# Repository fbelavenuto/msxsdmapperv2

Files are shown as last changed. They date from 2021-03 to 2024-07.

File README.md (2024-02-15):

# MSX SD Mapper V2

## WARNING: do not try to update the old SDMapper V1 (and its clones) with this new ROM using the old SDMUPD.COM utility, as the hardware is different, and it will brick your cartridge.

# Disclaimer

This documentation describes Open Hardware and is licensed under the CERN OHL v. 1.1.

You may redistribute and modify this documentation under the terms of the [CERN OHL v.1.1](http://ohwr.org/cernohl). This documentation is distributed WITHOUT ANY EXPRESS OR IMPLIED WARRANTY, INCLUDING OF MERCHANTABILITY, SATISFACTORY QUALITY AND FITNESS FOR A PARTICULAR PURPOSE.

Please see the CERN OHL v.1.1 for applicable conditions

# Project description

This project implements a cartridge-shaped interface to add a mass storage device using up to two SD (Secure Digital) and a 512K Mapper for MSX line computers.

[Nextor](http://www.konamiman.com/msx/msx-e.html#nextor) was used as operating system, being developed only the driver to have access to the two SD cards. Nextor is an open project.

Nextor is an evolution of MSX-DOS 2 natively supporting FAT16 partitions up to 4GB, and can have 4 partitions per SD card. 128KB of Mapper is required on the minimum to use Nextor with access to sub-directories, less than 128K mapper only allows the use of the MSXDOS1 kernel, limiting partitions with FAT12 and maximum 16MB per partition.

One of the switches enables or disables the Mapper in conjunction with a slot expander. The second key allows you to select between two driver options, useful for having a backup a stable version of the driver and use it to restore a new driver update failed.

A utility called "FBL-UPD.COM" was created to be able to update the flash by MSX itself.

To compile the FBL-UPD.COM driver and utility use the [Konaniman's Nestor80](https://github.com/Konamiman/Nestor80) and to compile the CPLD code use [Xilinx ISE Webpack](https://www.xilinx.com/support/download/index.html/content/xilinx/en/downloadNav/vivado-design-tools/archive-ise.html).

Technical details:
 - The CPLD code implements all the necessary logic, implementing an expander of standard slots, one SPI mode 0 port, standard ASCII16 MegaROM control used by Nextor and the 512K Mapper control.
 - When activating the mapper, the interface activates the slot expander, and with that the interface works only on non-expanded slots. However, if you disable the mapper, the slot expander is disabled, allowing you to use the device of mass storage in expanded slots. the mass storage device is in subslot 0 and the mapper device in subslot 1.
 - There is a window in $7B00~7EFF for SPI data transfer.
 - There is a configuration and status register at address $7FF0 and a small timer at address $7FF1. More details in the driver source.

# Acknowledge

Thanks to FRS for rewriting the driver, to Luciano Sturaro for board routing and the MSXBR-L community for their support and encouragement.

# Quickstart guide

After assembling the device, or buying a ready-made one, get an SD card, put it in the interface and start MSX.

When dropping into BASIC, type `CALL FDISK` to start formatting the SD card. The FAT16 file system used by Nextor supports a maximum of 4GB.

After partitioning and formatting, shut down MSX, remove the SD card and put it on your PC, copy the contents of the ./SD folder into the first partition of the SD card and put it back in MSX.

For more information on how to use Nextor, visit [User Manual](https://github.com/Konamiman/Nextor/blob/v2.1/docs/Nextor%202.1%20User%20Manual.md)

# 3D case

I found [this design](https://www.printables.com/en/model/496236-msx-cartridge-for-fblabs-sd-mapper-v2) made by community.

# Readme in portuguese

Este projeto implementa uma interface em forma de cartucho para adicionar um dispositivo de armazenamento em massa utilizando até dois cartões SD (Secure Digital) e uma Mapper de 512K para computadores da linha MSX.

Foi utilizado como sistema operacional o [Nextor](http://www.konamiman.com/msx/msx-e.html#nextor) sendo desenvolvido somente o driver para se ter acesso aos dois cartões SD. O Nextor é um projeto aberto.

O Nextor é uma evolução do MSX-DOS 2 tendo nativamente suporte a partições FAT16 de até 4GB, podendo ter 4 partições por cartão SD. É necessário 128KB de Mapper no mínimo para utilizar o Nextor com acesso à sub-diretórios, menos que 128K de mapper permite somente o uso do kernel do MSXDOS1 limitando em partições com FAT12 e máximo de 16MB por partição.

Uma das chaves habilita ou não a Mapper em conjunto com um expansor de slot. A segunda chave permite selecionar entre duas opções de driver, útil para se ter um backup de uma versão estável do driver e utilizá-lo para restaurar um driver novo com falha na atualização.

Foi criado um utilitário chamado "FBL-UPD.COM" para poder atualizar a flash pelo próprio MSX.

Para compilar o driver e o utilitário FBL-UPD.COM utilize o [Nestor80 do Konaniman](https://github.com/Konamiman/Nestor80) e para compilar o código do CPLD utilize o [Xilinx ISE Webpack](https://www.xilinx.com/support/download/index.html/content/xilinx/en/downloadNav/vivado-design-tools/archive-ise.html).

# Agradecimentos

Agradecimentos ao FRS pela re-escrita do driver, ao Luciano Sturaro pelo roteamento da placa e a comunidade MSXBR-L pelo apoio e incentivo.

# Detalhes técnicos:

 - O código do CPLD implementa toda a lógica necessária, implementando um expansor de slots padrão, uma porta SPI modo 0, o controle da MegaROM padrão ASCII16 utilizada pelo Nextor e o controle da Mapper de 512K.
 - Ao ativar a mapper, a interface ativa o expansor de slots, e com isso a interface funciona somente em slots não-expandidos. Porém, se desativar a mapper, o expansor de slots é desativado, permitindo utilizar o dispositivo de armazenamento em massa em slots expandidos. O dispositivo de armazenamento em massa fica no subslot 0 e a mapper no subslot 1.
 - Há uma janela em $7B00~7EFF para a transferência de dados SPI.
 - Existe um registro de configuração e status no endereço $7FF0 e um pequeno timer no endereço $7FF1. Mais detalhes no source do driver.

# Início rápido

Depois de montar o dispositivo, ou comprar um pronto, adquira um cartão SD, coloque na interface e inicie o MSX.

Ao cair no BASIC, digite `CALL FDISK` para iniciar a formatação do cartão SD. O sistema de arquivos FAT16 utilizado pelo Nextor suporta no máximo 4GB.

Após o particionamento e formatação, desligue o MSX, retire o cartão SD e coloque no seu PC, copie o conteúdo da pasta ./SD para dentro da primeira partição do cartão SD e recoloque no MSX.

Maiores informações de como usar o Nextor acesse o [Manual do usuário](https://github.com/Konamiman/Nextor/blob/v2.1/docs/Nextor%202.1%20User%20Manual.md)

# Case 3D

Eu achei [este desenho](https://www.printables.com/en/model/496236-msx-cartridge-for-fblabs-sd-mapper-v2) feito pela comunidade.

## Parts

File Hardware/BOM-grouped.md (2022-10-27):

# Bill of Materials (grouped)

## Resistors

### All are SMD 0805 resistors

| Qtd | Value | Obs |
|:----:|---|-----|
| 1 | 330Ω  | |
| 8 | 4K7 | |

## Capacitors

| Qtd | Value | Type | Obs |
|:---:|---|---|-----|
|  8  | 100n  | SMD ceramic 0805 | |
|  1  | 100u/6V3 | SMD EUC | Mutually exclusive with the next |
|  1  | 100u/16V | Eletrolitic 3,5-6 | Mutually exclusive with the previous |

## Transistors

| Qtd | Model | Type |
|:---:|---|---|
| 2 | BC858 | SOT23-BEC |

## Diodes (LEDs)

| Qtd | Value | Obs |
|:---:|---|-----|
| 2 | 3mm | Any color |

## Xtal

| Qtd | Value | Obs |
|:---:|---|-----|
| 1 | 25MHz | SMD model SM77H 3V3 |

## Integrated Circuits

| Qtd | Value | Obs |
|:---:|---|-----|
| 1 | XC95144XL | CPLD Xilinx TQ100 |
| 1 | 628512 | SRAM 4Mbit SOP32 |
| 1 | *See note #1 | PLCC32 |
| 2 | LM1117-3V3 | SOT223 |

### Note #1 - Possible models: SST39SF020, AT49F002, AT49F002T, SST39SF020, W49F002UN or W49F002B

## Others

| Qtd | Value | Model |
|:---:|---|---|
| 2 | SD MMC card holder | 06132 |
| 2 | Tiny switch | TL32YO |

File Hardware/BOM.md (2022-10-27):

# Bill of Materials

| Part | Value | Package | Description |
|:----:|---|---|---|
| R1 | 4K7 | 0805 | Resistor |
| R2 | 4K7 | 0805 | Resistor |
| R3 | 330 | 0805 | Resistor |
| R4 | 4K7 | 0805 | Resistor |
| R5 | 4K7 | 0805 | Resistor |
| R6 | 4K7 | 0805 | Resistor |
| R7 | 4K7 | 0805 | Resistor |
| R8 | 4K7 | 0805 | Resistor |
| R9 | 4K7 | 0805 | Resistor |
| C1 | 100u | E3,5-6 | Polarized capacitor (see note #1) |
| C2 | 100u | SMD EUC | Polarized capacitor (see note #1) |
| C3 | 100n | SMD 0805 | Capacitor |
| C4 | 100n | SMD 0805 | Capacitor |
| C5 | 100n | SMD 0805 | Capacitor |
| C6 | 100n | SMD 0805 | Capacitor |
| C7 | 100n | SMD 0805 | Capacitor |
| C8 | 100n | SMD 0805 | Capacitor |
| C9 | 100n | SMD 0805 | Capacitor |
| C10 | 100n | SMD 0805 | Capacitor |
| D1 | Cart1 | 3mm | LED 3mm any color |
| D2 | Cart2 | 3mm | LED 3mm any color |
| T1 | BC858 | SOT23-BEC | PNP Transistor |
| T2 | BC858 | SOT23-BEC | PNP Transistor |
| X1 | 25MHz | SM77H | 3.3V CMOS Clock Oscillator |
| IC1 | *see note #2 | PLCC32 | 2 Mbit x8 Multi-Purpose Flash |
| IC2 | 628512 | SOP32 | 4M SRAM 512kword x 8bit |
| IC3 | XC95144XL |TQ100 | XC95144XL-TQ100 |
| IC4 | LM1117-3V3 | SOT223 | Voltage Regulator LM1117
| IC5 | LM1117-3V3 | SOT223 | Voltage Regulator LM1117
| S1 | TL32YO | TL3XYO | TINY SWITCH ON - MOM |
| S2 | TL32YO | TL3XYO | TINY SWITCH ON - MOM |
| SD1 | SDMMC06132 | 06132 | SD MMC Card holder |
| SD2 | SDMMC06132 | 06132 | SD MMC Card holder |

### Notes:
 - 1 - Use C1 or C2
 - 2 - Possible models: SST39SF020, AT49F002, AT49F002T, SST39SF020, W49F002UN or W49F002B

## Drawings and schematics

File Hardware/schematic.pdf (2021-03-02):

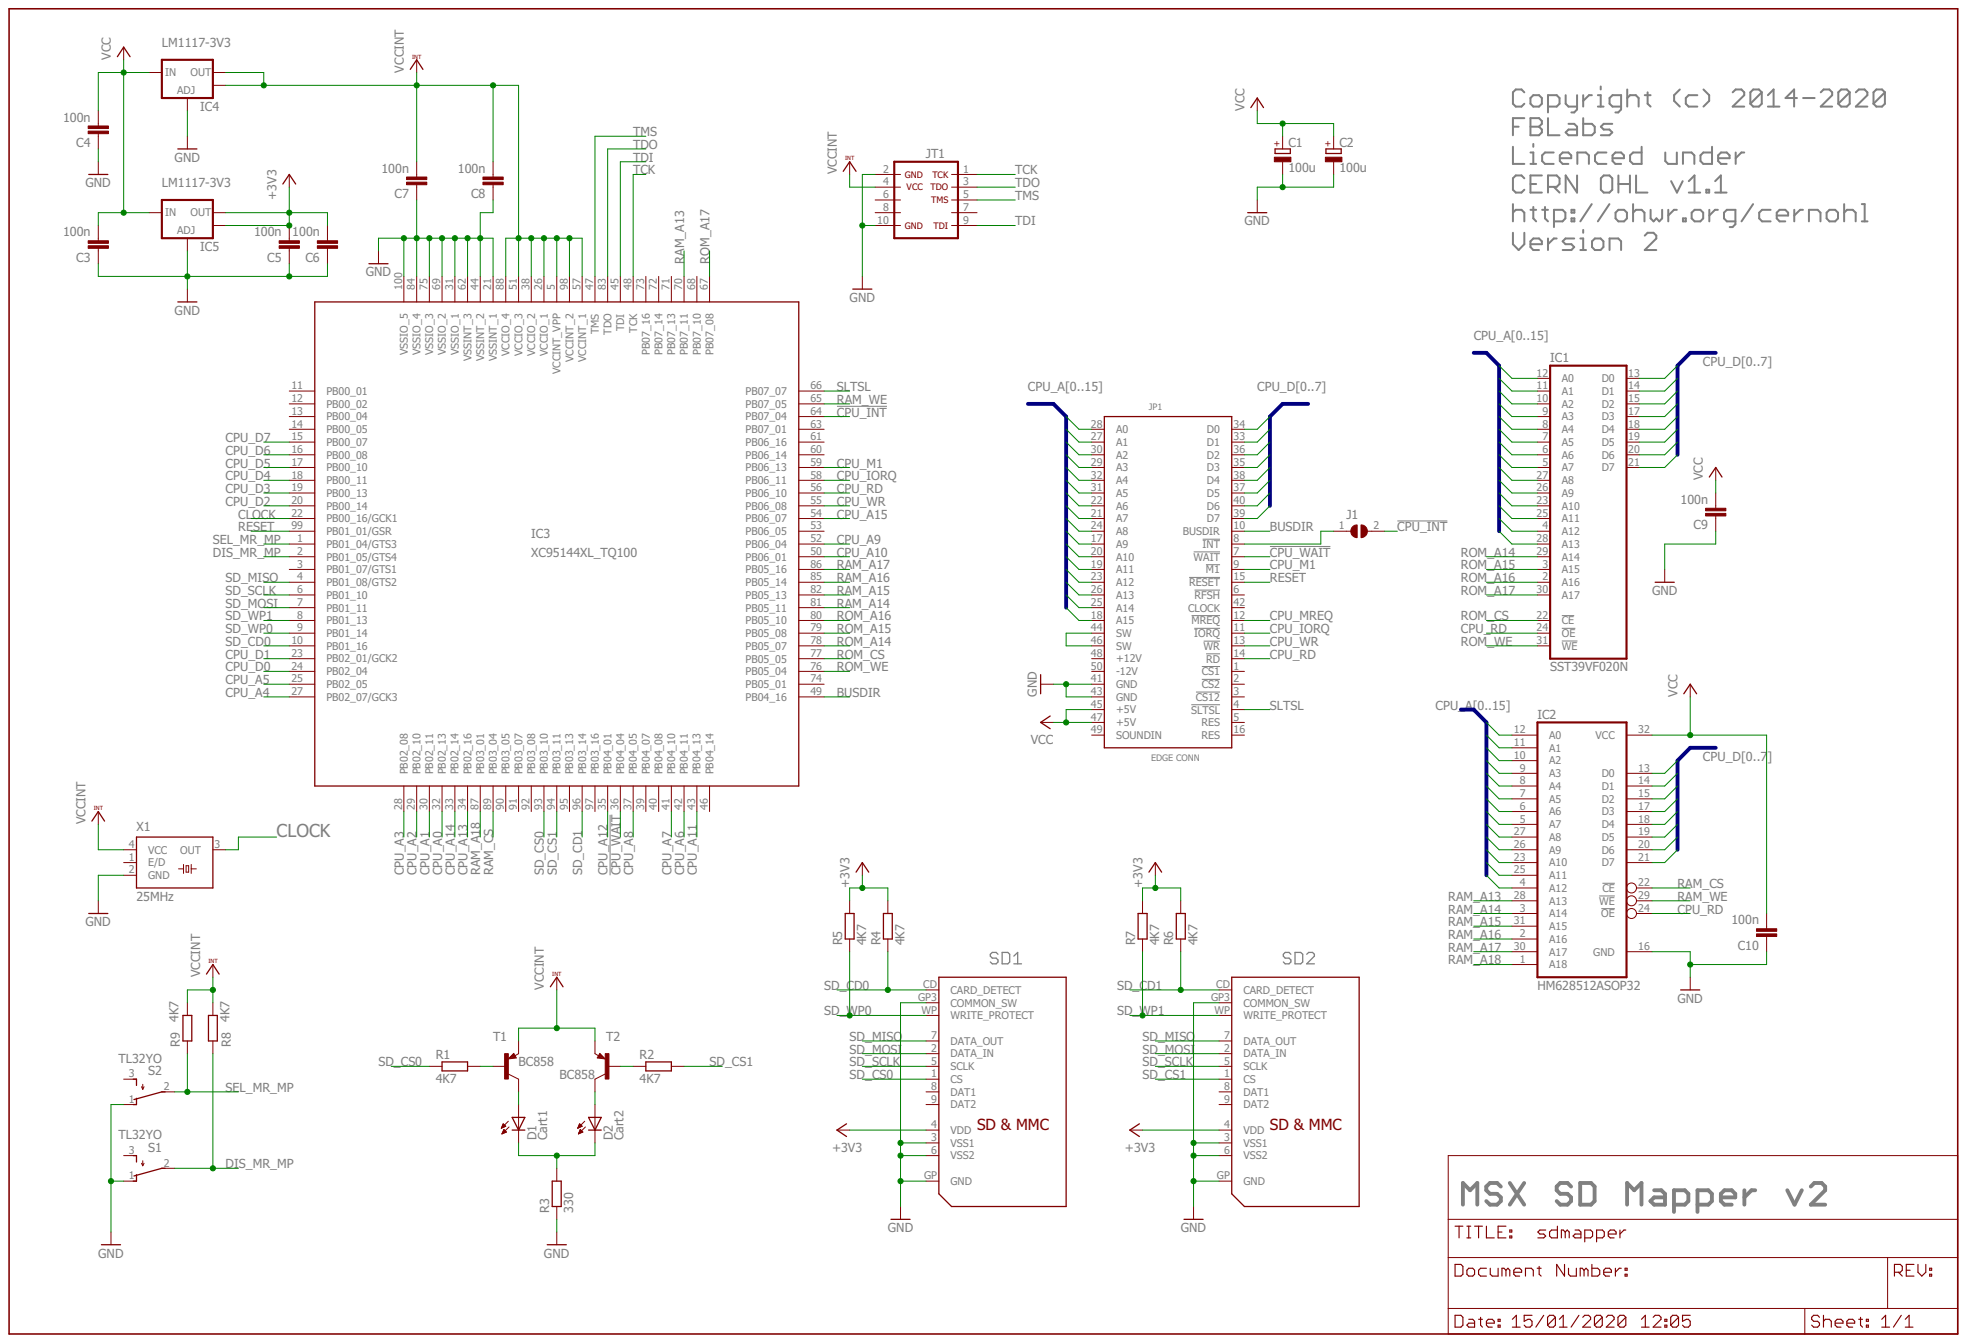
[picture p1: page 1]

6 8 10 | 5

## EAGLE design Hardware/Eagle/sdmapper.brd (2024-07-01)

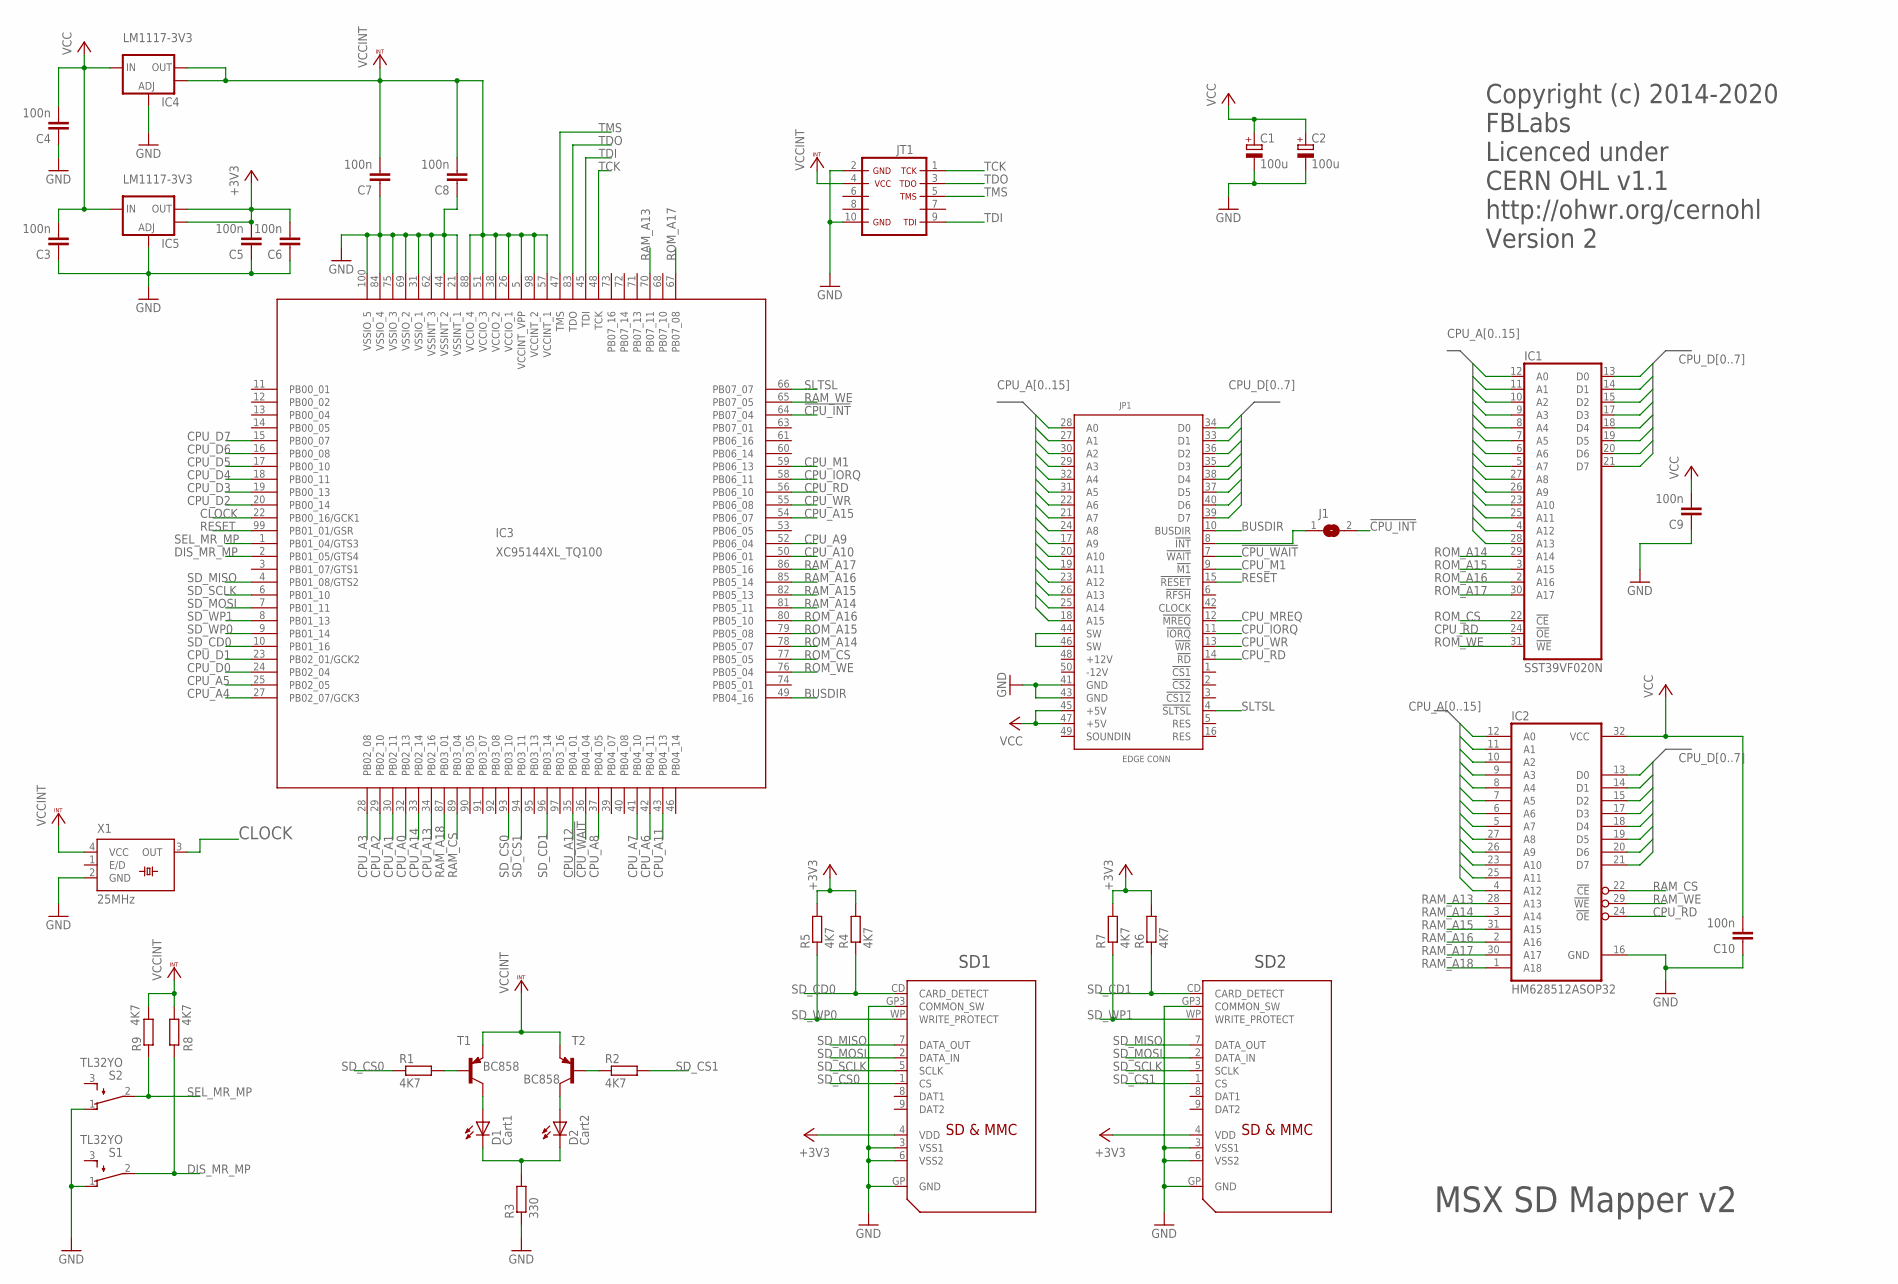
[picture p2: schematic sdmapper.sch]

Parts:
C1: 100u; E3,5-6
C2: 100u; PANASONIC_C
C3, C4, C5, C6, C7, C8, C9, C10: 100n; C0805
D1: Cart1; LED3MM
D2: Cart2; LED3MM
IC1: SST39VF020N; PLCC32R
IC2: HM628512ASOP32; SOP32
IC3: XC95144XL_TQ100; XC-TQ100
IC4, IC5: LM1117-3V3; SOT223
J1: SJ4; SJ20
JP1: MSXCART1; MSXCART
JT1: JTAG1B; SMD5X2
R1, R2, R4, R5, R6, R7, R8, R9: 4K7; R0805
R3: 330; R0805
S1, S2: TL32YO; TL3XYO
SD1, SD2: SDMMC06132; 06132
T1, T2: BC858; SOT23-BEC
X1: 25MHz; SM77H

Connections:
!CPU_INT: IC3.64 (PB07_04), J1.2
!CPU_WAIT: IC3.36 (PB04_04), JP1.7 (!WAIT)
+3V3: C5.2, C6.2, IC5.2 (OUT), IC5.4 (OUT), R4.2, R5.2, R6.2, R7.2, SD1.4 (VDD), SD2.4 (VDD)
BUSDIR: IC3.49 (PB04_16), JP1.10 (BUSDIR)
CLOCK: IC3.22 (PB00_16/GCK1), X1.3 (OUT)
CPU_A0: IC1.12 (A0), IC2.12 (A0), IC3.32 (PB02_13), JP1.28 (A0)
CPU_A1: IC1.11 (A1), IC2.11 (A1), IC3.30 (PB02_11), JP1.27 (A1)
CPU_A2: IC1.10 (A2), IC2.10 (A2), IC3.29 (PB02_10), JP1.30 (A2)
CPU_A3: IC1.9 (A3), IC2.9 (A3), IC3.28 (PB02_08), JP1.29 (A3)
CPU_A4: IC1.8 (A4), IC2.8 (A4), IC3.27 (PB02_07/GCK3), JP1.32 (A4)
CPU_A5: IC1.7 (A5), IC2.7 (A5), IC3.25 (PB02_05), JP1.31 (A5)
CPU_A6: IC1.6 (A6), IC2.6 (A6), IC3.42 (PB04_11), JP1.22 (A6)
CPU_A7: IC1.5 (A7), IC2.5 (A7), IC3.41 (PB04_10), JP1.21 (A7)
CPU_A8: IC1.27 (A8), IC2.27 (A8), IC3.37 (PB04_05), JP1.24 (A8)
CPU_A9: IC1.26 (A9), IC2.26 (A9), IC3.52 (PB06_04), JP1.17 (A9)
CPU_A10: IC1.23 (A10), IC2.23 (A10), IC3.50 (PB06_01), JP1.20 (A10)
CPU_A11: IC1.25 (A11), IC2.25 (A11), IC3.43 (PB04_13), JP1.19 (A11)
CPU_A12: IC1.4 (A12), IC2.4 (A12), IC3.35 (PB04_01), JP1.23 (A12)
CPU_A13: IC1.28 (A13), IC3.34 (PB02_16), JP1.26 (A13)
CPU_A14: IC3.33 (PB02_14), JP1.25 (A14)
CPU_A15: IC3.54 (PB06_07), JP1.18 (A15)
CPU_D0: IC1.13 (D0), IC2.13 (D0), IC3.24 (PB02_04), JP1.34 (D0)
CPU_D1: IC1.14 (D1), IC2.14 (D1), IC3.23 (PB02_01/GCK2), JP1.33 (D1)
CPU_D2: IC1.15 (D2), IC2.15 (D2), IC3.20 (PB00_14), JP1.36 (D2)
CPU_D3: IC1.17 (D3), IC2.17 (D3), IC3.19 (PB00_13), JP1.35 (D3)
CPU_D4: IC1.18 (D4), IC2.18 (D4), IC3.18 (PB00_11), JP1.38 (D4)
CPU_D5: IC1.19 (D5), IC2.19 (D5), IC3.17 (PB00_10), JP1.37 (D5)
CPU_D6: IC1.20 (D6), IC2.20 (D6), IC3.16 (PB00_08), JP1.40 (D6)
CPU_D7: IC1.21 (D7), IC2.21 (D7), IC3.15 (PB00_07), JP1.39 (D7)
CPU_IORQ: IC3.58 (PB06_11), JP1.11 (!IORQ)
CPU_M1: IC3.59 (PB06_13), JP1.9 (!M1)
CPU_MREQ: JP1.12 (!MREQ)
CPU_RD: IC1.24 (!OE), IC2.24 (!OE), IC3.56 (PB06_10), JP1.14 (!RD)
CPU_WR: IC3.55 (PB06_08), JP1.13 (!WR)
DIS_MR_MP: IC3.2 (PB01_05/GTS4), R8.1, S1.2
GND: C1.-, C2.-, C3.1, C4.1, C5.1, C6.1, C7.1, C8.1, C9.1, C10.1, IC1.16 (GND), IC2.16 (GND), IC3.21 (VSSINT_1), IC3.31 (VSSIO_1), IC3.44 (VSSINT_2), IC3.62 (VSSINT_3), IC3.69 (VSSIO_2), IC3.75 (VSSIO_3), IC3.84 (VSSIO_4), IC3.100 (VSSIO_5), IC4.1 (ADJ), IC5.1 (ADJ), JP1.41 (GND), JP1.43 (GND), JT1.2, JT1.10, R3.1, S1.1 (O), S2.1 (O), SD1.3 (VSS1), SD1.6 (VSS2), SD1.GP (GND), SD1.GP3 (COMMON_SW), SD2.3 (VSS1), SD2.6 (VSS2), SD2.GP (GND), SD2.GP3 (COMMON_SW), X1.2 (GND)
unnamed: JP1.44 (SW), JP1.46 (SW)
unnamed: J1.1, JP1.8 (!INT)
unnamed: R1.2, T1.B
unnamed: R2.1, T2.B
unnamed: D1.K (C), D2.K (C), R3.2
unnamed: D1.A, T1.C
unnamed: D2.A, T2.C
RAM_A13: IC2.28 (A13), IC3.70 (PB07_11)
RAM_A14: IC2.3 (A14), IC3.81 (PB05_11)
RAM_A15: IC2.31 (A15), IC3.82 (PB05_13)
RAM_A16: IC2.2 (A16), IC3.85 (PB05_14)
RAM_A17: IC2.30 (A17), IC3.86 (PB05_16)
RAM_A18: IC2.1 (A18), IC3.87 (PB03_01)
RAM_CS: IC2.22 (!CE), IC3.89 (PB03_04)
RAM_WE: IC2.29 (!WE), IC3.65 (PB07_05)
RESET: IC3.99 (PB01_01/GSR), JP1.15 (!RESET)
ROM_A14: IC1.29 (A14), IC3.78 (PB05_07)
ROM_A15: IC1.3 (A15), IC3.79 (PB05_08)
ROM_A16: IC1.2 (A16), IC3.80 (PB05_10)
ROM_A17: IC1.30 (A17), IC3.67 (PB07_08)
ROM_CS: IC1.22 (!CE), IC3.77 (PB05_05)
ROM_WE: IC1.31 (!WE), IC3.76 (PB05_04)
SD_CD0: IC3.10 (PB01_16), R4.1, SD1.CD (CARD_DETECT)
SD_CD1: IC3.96 (PB03_14), R6.1, SD2.CD (CARD_DETECT)
SD_CS0: IC3.93 (PB03_10), R1.1, SD1.1 (CS)
SD_CS1: IC3.94 (PB03_11), R2.2, SD2.1 (CS)
SD_MISO: IC3.4 (PB01_08/GTS2), SD1.7 (DATA_OUT), SD2.7 (DATA_OUT)
SD_MOSI: IC3.7 (PB01_11), SD1.2 (DATA_IN), SD2.2 (DATA_IN)
SD_SCLK: IC3.6 (PB01_10), SD1.5 (SCLK), SD2.5 (SCLK)
SD_WP0: IC3.9 (PB01_14), R5.1, SD1.WP (WRITE_PROTECT)
SD_WP1: IC3.8 (PB01_13), R7.1, SD2.WP (WRITE_PROTECT)
SEL_MR_MP: IC3.1 (PB01_04/GTS3), R9.1, S2.2
SLTSL: IC3.66 (PB07_07), JP1.4 (!SLTSL)
TCK: IC3.48 (TCK), JT1.1
TDI: IC3.45 (TDI), JT1.9
TDO: IC3.83 (TDO), JT1.3
TMS: IC3.47 (TMS), JT1.5
VCC: C1.+, C2.+, C3.2, C4.2, C9.2, C10.2, IC1.32 (VCC), IC2.32 (VCC), IC4.3 (IN), IC5.3 (IN), JP1.45 (+5V), JP1.47 (+5V)
VCCINT: C7.2, C8.2, IC3.5 (VCCINT_VPP), IC3.26 (VCCIO_1), IC3.38 (VCCIO_2), IC3.51 (VCCIO_3), IC3.57 (VCCINT_1), IC3.88 (VCCIO_4), IC3.98 (VCCINT_2), IC4.2 (OUT), IC4.4 (OUT), JT1.4, R8.2, R9.2, T1.E, T2.E, X1.4 (VCC)

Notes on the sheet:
MSX SD Mapper v2
Copyright (c) 2014-2020 FBLabs Licenced under CERN OHL v1.1 http://ohwr.org/cernohl Version 2
SD1
SD2

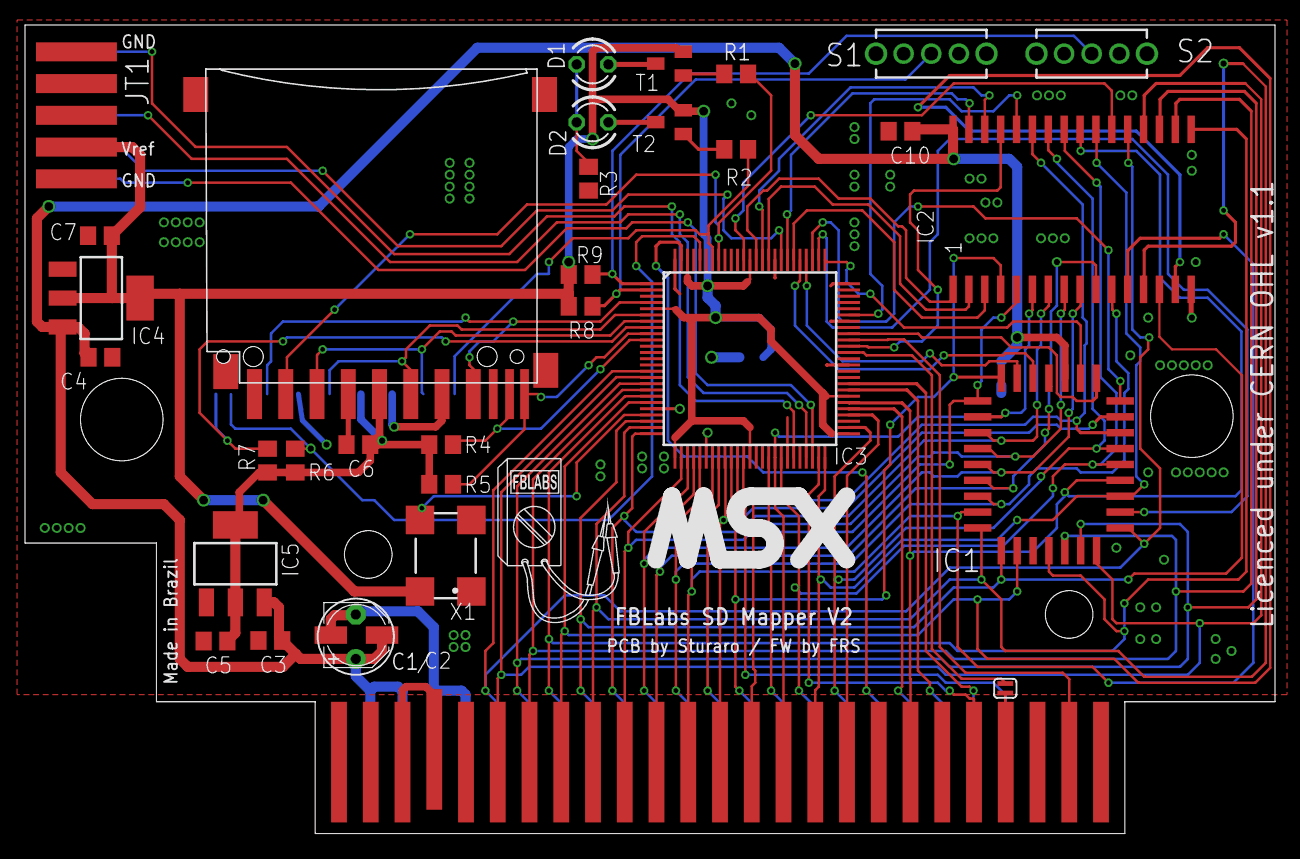
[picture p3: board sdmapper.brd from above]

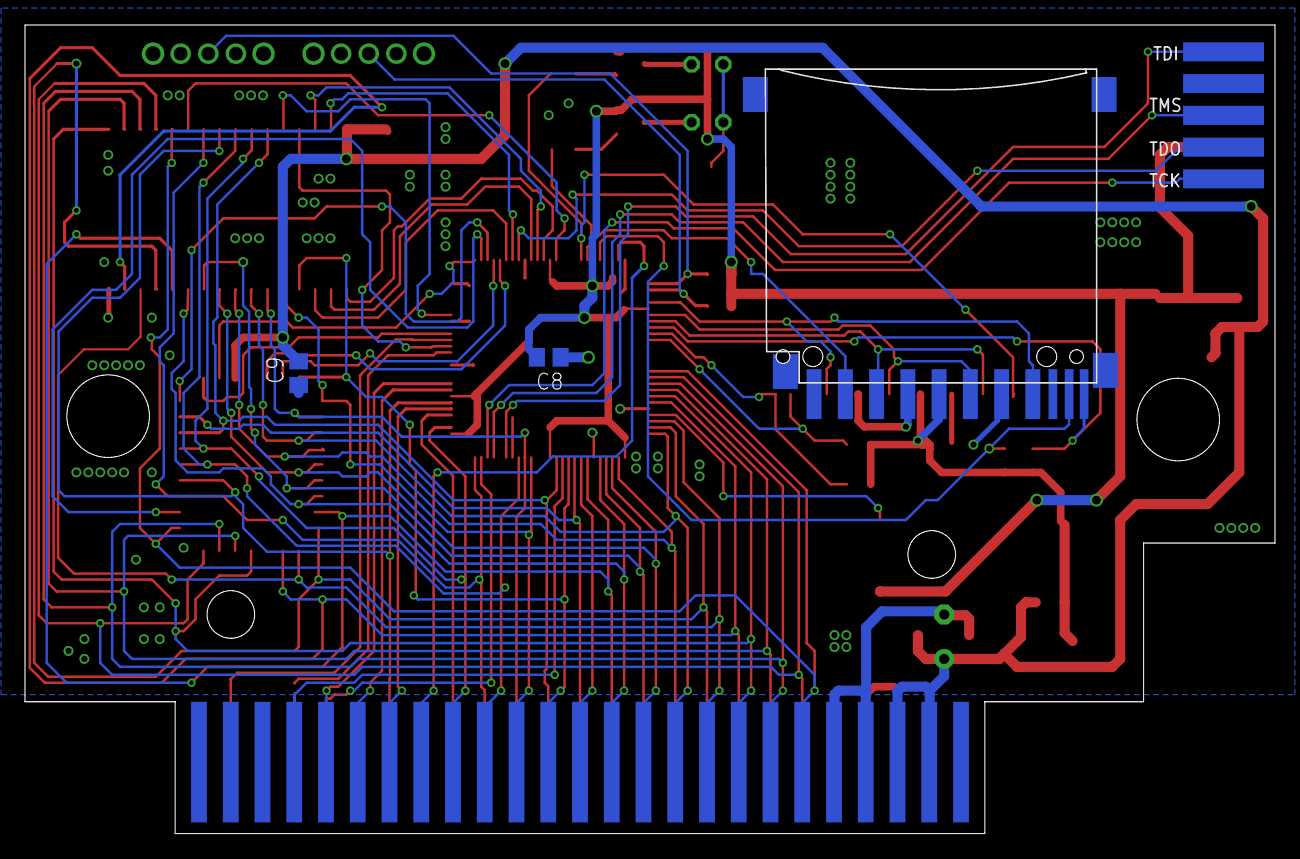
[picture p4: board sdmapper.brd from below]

Board: 2 copper layers, 100.0 x 64.7 mm, 38 parts (3 on the bottom side), 74 nets.

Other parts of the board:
U$1: LOGO_FABIO_SILK_400MIL
U$3: MSX_SILK

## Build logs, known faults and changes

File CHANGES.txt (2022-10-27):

01/01/2020:
Tirado porta I/O criada para atualização. Modificado forma de atualização para ASCII16 padrão.
Frame 1 para leitura da Flash, Frame 2 para leitura e escrita somente se banco > 7.
Adicionado detecção do disk change.
Melhorado modo assíncrono da porta SPI.
Registro para seleção dos bancos das páginas agora é decodificado completo, 6000h e 7000h.
Janela SPI sempre ativa agora.
Mudado registros:
 - Para acesso aos dados do SPI a janela é 7B00h a 7EFFh.
 - Para controle e status é 7F00h
Mudado forma de seleção do cartão atual, bits 1 e 0 do registro 7F00h seleciona cartão:
 - "00" não seleciona nenhum;
 - "01" seleciona 1º cartão;
 - "10" seleciona 2º cartão.
Para ler status, depende do cartão selecionado, se nenhum lê status das chaves externas, se algum 
 selecionado lê status do disk change, cartão inserido e proteção contra escrita.

04/11/2014:
  Atualizado versão no Nextor para 2.0.4

06/07/2014:
  Alterado lógica do CPLD para porta SPI trabalhar assincronicamente. Não
é mais necessário depender do clock do barramento.

15/01/2014:
  Adicionado circuito da Megaram (by Ademir Carchano) e uma chave para poder
selecionar se a interface irá implementar uma Mapper ou uma Megaram.
  Layout da PCB desenhado pelo Luciano Sturaro.

02/01/2014:
  Primeira versão.

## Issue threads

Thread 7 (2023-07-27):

Yis503III and memory mapper

serperus, 2023-07-27:
Hi,
After assembling the cartrige I checked it on Omega MSX and it works great, both SD are visible and addditional 512k RAM - ok.
But I can't run it on YIS503-III Yamaha,
SD cards are detected, nextor runs good to dos,  but 512k RAM - not visible.
Any game from sofarun says out of free segments, and testmap can't see additional mapper in slot.

Is it compatible with this msx machine?
Thanks!

Serge

fbelavenuto, 2023-12-04:
Hello, sorry for the delay. I don't have a YIS503-III to test, but it is possible that there is incompatibility with this model. Some MSX models that I had access to test are incompatible with SDMapper.

serperus, 2023-12-04:
Hi,
The problem was solved by adding additional internal 1M to YIS503 machine :)
512k still not visible, but sd works.

Closed 2023-12-11.

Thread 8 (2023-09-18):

Sony HB-101 - IC8 M38128A

DRAKE9800, 2023-09-18:
There is a conflict when using this project with Sony HB-101 involving the built in software suite. When booting it is possible to see the presence of the device and SD card via MSX basic but the machine is unable to boot from the SD due to the proprietary nature of the ROM at IC8.

A solution was to de-solder IC8 (putting sockets in it's place for future use) and boot the machine without it. This lets the machine boot directly into MSX basic and the Mapper. With an autoexec.bat to call on utilities such as SofaRun users will be able to boot directly into their chosen software.
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

fbelavenuto, 2023-12-04:
Thanks for the comment

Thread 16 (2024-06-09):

SDMapper 1.1.0 Nextor 2.1.2 does not work on Panasonic FS-A1.

joyprogram, 2024-06-09:
The firmware has been updated to SDMapper 1.1.0 Nextor 2.1.2 for SD Mapper V2.
The switch put S1 on the right (512KB Rammapper enabled) and S2 on the left (firmware enabled).
SDMapper 1.1.0 Nextor 2.1.2 does not work on Panasonic FS-A1.
When booting from Panasonic FS-A1, hold down the DEL key and BASIC will appear after recognizing the SD card.
It works well on other Japanese MSX models, but it doesn't work on the Panasonic FS-A1.
Please solve the problem.

joyprogram, 2024-06-11:
Problem solved.
The cause was Flash ROM.
After replacing the Flash ROM, it works fine on Panasonic FS-A1.

Closed 2024-06-11.

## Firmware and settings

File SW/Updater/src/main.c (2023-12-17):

/*
Copyright (c) 2017 FBLabs

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
You should have received a copy of the GNU General Public License
along with this program.  If not, see <http://www.gnu.org/licenses/>.
*/

#include "conio.h"
#include "strings.h"
#include "mem.h"
#include "bios.h"
#include "msxdos.h"
#include "mapper.h"
#include "interface.h"


/* Structs */

/* Constants */
const unsigned char *EXPTBL = (volatile unsigned char *)0xFCC1;	// slots expanded or not
const unsigned char *DSKSLT = (volatile unsigned char *)0xF348;	// slotid diskrom


/* Global vars */
//unsigned char *HKEYI = (volatile unsigned char *)0xFD9A;
unsigned char *HTIMI = (volatile unsigned char *)0xFD9F;
//unsigned char *HCHPU = (volatile unsigned char *)0xFDA4;

static TDevInfo devInfo;
static unsigned char numMprPages, mprSegments[8], curSegm;
static unsigned char hooks[1], pfi, askslot, onlyErase, resetAtEnd;
static unsigned char buffer[64], pause;
static unsigned char c, t1, t2, slot, swId, isMain, isSlave;
static int fhandle, i, r;
static unsigned long fileSize, seekpos;


/******************************************************************************/
static void restoreHooks()
{
	// Restore hooks
	*HTIMI = hooks[0];
	//*HCHPU = hooks[1];
}

/******************************************************************************/
int main(char** argv, int argc)
{
	puts(title1);
	puts(title2);

	if (argc < 1) {
showUsage:
		puts(usage1);
		puts(usage2);
		puts(usage3);
		return 1;
	}
	pfi = 0;
	onlyErase = 0;
	askslot = 0;
	pause = 0;
	for (i = 0; i < argc; i++) {
		if (argv[i][0] == '/') {
			if (argv[i][1] == 'h' || argv[i][1] == 'H') {
				puts(usage1);
				puts(usage2);
				puts(usage3);
				return 0;
			} else if (argv[i][1] == 'e' || argv[i][1] == 'E') {
				onlyErase = 1;
				++pfi;
			} else if (argv[i][1] == 's' || argv[i][1] == 'S') {
				askslot = 1;
				++pfi;
			} else if (argv[i][1] == 'p' || argv[i][1] == 'P') {
				pause = 1;
				++pfi;
			} else {
				goto showUsage;
			}
		}
	}
	if (pfi == argc && onlyErase == 0) {
		goto showUsage;
	}

	// Save hooks
	hooks[0] = *HTIMI;
	//hooks[1] = *HCHPU;
	// Temporary disable hooks
	*HTIMI = 0xC9;
	//*HCHPU = 0xC9;

	if (askslot == 1) {
		puts(whatslot);
		while(1) {
			c = getchar();
			if (c >= '0' && c <= '3') {
				break;
			}
		}
		putchar(c);
		puts(crlf);
		slot = c - '0';
		if ((*(EXPTBL+slot) & 0x80) == 0x80) {
			puts(whatsubslot);
			while(1) {
				c = getchar();
				if (c >= '0' && c <= '3') {
					break;
				}
			}
			putchar(c);
			puts(crlf);
			c -= '0';
			slot |= 0x80 | (c << 2);
		}
		if (detectInterface(slot) == 0) {
			slot = 0xFF;
		}
		puts(crlf);
	} else {
		// Find interface
		puts(searching);
		slot = (*EXPTBL) & 0x80;
		while (1) {
			if (slot == 0x8F || slot == 0x03) {
				slot = 0xFF;
				break;
			}
			if (detectInterface(slot) == 1) {
				puts(found3);
				putdec8(slot & 0x03);
				if ((slot & 0x80) == 0x80) {
					putchar('.');
					putdec8((slot & 0x0C) >> 2);
				}
				puts(crlf);
				break;
			}
			// Next slot
			if (slot & 0x80) {
				if ((slot & 0x0C) != 0x0C) {
					slot += 0x04;
					continue;
				}
			}
			slot = (slot & 0x03) + 1;
			slot |= (*(EXPTBL+slot)) & 0x80;
		}
	}

	if (slot == 0xFF) {
		restoreHooks();
		puts(notfound);
		return 4;
	}

	// Detects MSXDOS version
	msxdos_init();

	/* If is MSXDOS1, we can not verify which is the main DOS, we assume it is. */
	if (dosversion < 2 || *DSKSLT == slot) {
		isMain = 1;
	} else {
		isMain = 0;
	}

	isSlave = 0;
	if (dosversion == 0x82) {			// Is Nextor, check devices
		for (c = 0; c < 16; c++) {
			if (0 == getDeviceInfo(c, &devInfo)) {
				if (devInfo.slotNum == slot) {
					isSlave = 1;
				}
			}
		}
	} else {
		isSlave = 1;					// Forces a reset
	}

	if (onlyErase == 1) {
		if (isMain == 1 || isSlave == 1) {
			puts(confirmReset0);
			puts(confirmReset1);
			puts(confirmReset3);
			clearKeyBuf();
			c = getchar();
			putchar(c);
			puts(crlf);
			if (c == 'y' || c == 'Y') {
				__asm__("di");
				eraseFlash(slot);
				resetSystem();
			}
			restoreHooks();
			return 0;
		} else {
			eraseFlash(slot);
			restoreHooks();
			return 0;
		}
	}

	c = mpInit();

	if (c != 0) {
		puts(errorNoExtBios);
		numMprPages = numMapperPages();
	} else {
		numMprPages = mpVars->numFree;
	}
	if (numMprPages < 8) {
		puts(noMemAvailable);
		restoreHooks();
		return 3;
	}
	// Saves the current segment;
	curSegm = getCurSegFrame1();

	// Try open file
	fhandle = open(argv[pfi], O_RDONLY);
	if (fhandle == -1) {
		puts(openingError);
		restoreHooks();
		return 4;
	}

	if (dosversion < 2) {
		fileSize = dos1GetFilesize();
	} else {
		fileSize = lseek(fhandle, 0, SEEK_END);
	}
	if (fileSize != 131072) {
		puts(filesizeError);
		restoreHooks();
		return 5;
	}
	/* Only for MSXDOS2 */
	if (dosversion > 1) {
		lseek(fhandle, 0x1C100, SEEK_SET);
		r = read(fhandle, buffer, 32);
		if (r == -1) {
			goto readErr;
		}
		if (memcmp(buffer, "NEXTOR_DRIVER", 13) == 1) {
			puts(errorNotNxtDrv);
			restoreHooks();
			return 6;		
		}
		if (verifySwId(buffer+16) == 0) {
			puts(errorWrongDrv);
			restoreHooks();
			return 7;
		}
		seekpos = lseek(fhandle, 0, SEEK_SET);
		if (seekpos != 0) {
			puts(errorSeek);
			restoreHooks();
			return 7;
		}
	} else {
		//
	}

	resetAtEnd = 0;
	if (isMain == 1 || isSlave == 1) {
		puts(confirmReset0);
		puts(confirmReset2);
		puts(confirmReset3);
		clearKeyBuf();
		c = getchar();
		putchar(c);
		puts(crlf);
		if (c == 'y' || c == 'Y') {
			resetAtEnd = 1;
		} else {
			close(fhandle);
			restoreHooks();
			return 0;
		}
	}

	for (i = 0; i < 8; i++) {
		mprSegments[i] = allocUserSegment();
		if (mprSegments[i] == 0) {
			puts(errorAllocMapper);
			close(fhandle);
			restoreHooks();
			return 10;
		}
	}
	puts(readingFile);
	c = 0;
	for (i = 0; i < 8; i++) {
		putchar(ce[c]);
		putchar(8);
		c = (c + 1) & 0x03;
		t1 = mprSegments[i];
		putSegFrame1(t1);
		r = read(fhandle, (void *)0x4000, 16384);
		putSegFrame1(curSegm);
		if (r != 16384) {
readErr:
			puts(readingError0);
			puthex8(last_error);
			puts(readingError1);
			close(fhandle);
			restoreHooks();
			return 11;
		}
	}
	puts(ok0);
	close(fhandle);

	if (pause == 1) {
		puts(pauseMsg);
		getchar();
		puts(crlf);
	}

	__asm__("di");
	eraseFlash(slot);

	puts(writingFlash);
	for (i = 0; i < 8; i++) {
		if (writeBlock(slot, mprSegments[i], curSegm, i) == 0) {
			break;
		}
	}
	__asm__("ei");
	if (i != 8) {
		puts(errorWriting);
		eraseFlash(slot);
		puts(systemHalted);
		__asm__("di");
		__asm__("halt");
	} else {
		putchar(' ');
		puts(ok0);
	}
	if (resetAtEnd == 1) {
		puts(anyKeyToReset);
		clearKeyBuf();
		getchar();
		resetSystem();
	}
	restoreHooks();
	return 0;
}

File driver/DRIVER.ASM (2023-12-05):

	.CPU Z80
	TITLE Nextor driver for SD Mapper v2 v1.1.0
	.relab

; Projeto MSX SD-Mapper v2

; Copyright (c) 2014 Fabio Belavenuto
; Copyright (c) 2017, 2018 Fabio R. Schmidlin 

; This documentation describes Open Hardware and is licensed under the CERN OHL v. 1.1.
; You may redistribute and modify this documentation under the terms of the
; CERN OHL v.1.1. (http://ohwr.org/cernohl). This documentation is distributed
; WITHOUT ANY EXPRESS OR IMPLIED WARRANTY, INCLUDING OF MERCHANTABILITY,
; SATISFACTORY QUALITY AND FITNESS FOR A PARTICULAR PURPOSE.
; Please see the CERN OHL v.1.1 for applicable conditions

; Technical info:
; The SD-Mapper v2 uses an ASCII16 ROM mapper and the following register set is only enabled at page-7.
;
; 7B00h~7EFFh	: SPI data transfer window (read/write)
; 7FF0h		: Interface status and card select register (read/write)
;	<read>
;	If no SD card is selected:
;	    b7-b2 : always 0
;	    b1 : SW1 status (Driver selection)
;	    b0 : SW0 status. 0=RAM disabled, 1=RAM enabled
;	If any SD card is selected:
;	    b7-b3 : always 0
;	    b2 : 1=Write protecton enabled for SD card-slot selected
;	    b1 : 0=SD card present in the selected card-slot
;	    b0 : 1=SD Card on slot selected changed since last read
;	<write>
;	    b0 : SD card slot-0 chip-select (1=selected)
;	    b1 : SD card slot-1 chip-select (1=selected)

; 7FF1h		: 8-bit timer (97.65625 KHz frequency, 10.24uS resolution) (read/write)
; When a value is written, the timer will decrease it until it reaches zero
;
;
; A Special thanks goes to Elm-chan, for publishing the documentation we used to
; create this driver. http://elm-chan.org/docs/mmc/mmc_e.html

;-----------------------------------------------------------------------------
;
; Driver configuration constants
;

CMDTIMEOUT	equ	2	; Command accepted timeout	: 2*2.6nS
READYTIMEOUT	equ	385	; Card ready timeout		: 10 second
DETTIMEOUT	equ	385	; Detection timeout		: 385*2.6nS = 1 second

; DEFINES
TURBOINIT 	equ 1	; Execute DRV_INIT with the turbo enabled 
DSKEMU 		equ 1	; Include a built-in floppy disk emulator
; PARALLELCARD	equ 1 	; Allows parallel card processing. Seems to require
			; independent communication lines for each card
; HASMEGARAM	equ 1	; Driver for an SD-Mapper with MegaRAM
; DEBUG1	equ 1	; Enable level-1 debugging (Only status queries)
; DEBUG2	equ 1	; Enable level-2 debugging (RW calls)
; DEBUG3	equ 1	; Enable level-3 debugging (requires level-1). Also logs invalid DEVs and LUN numbers


;Driver type:
;   0 for drive-based
;   1 for device-based

DRV_TYPE	equ	1

;Hot-plug devices support (device-based drivers only):
;   0 for no hot-plug support
;   1 for hot-plug support

DRV_HOTPLUG	equ	1


;Driver version

include "VERSION.INC"
;VER_MAIN	equ	1
;VER_SEC		equ	1
;VER_REV		equ	0

;-----------------------------------------------------------------------------
; SPI addresses. Check the Technical info above for the bit contents

SPIDATA		equ #7B00		; read/write
SPICTRL		equ #7FF0		; write
SPISTATUS	equ #7FF0		; read
TIMERREG	equ #7FF1		; read/write

; Interface status flags
IF_RAM		equ 0		; 1=Interface RAM is enabled
IF_DRVER	equ 1		; RAM mode: 0=MegaRAM, 1=MemoryMapper
IF_M_RAM	equ (1 shl IF_RAM)		; bitmask for IF_RAM
IF_M_DRVER	equ (1 shl IF_DRVER)		; bitmask for IF_DRVER

; card slot status flags
SD_DSKCHG	equ 0		; SD card changed since last status check
SD_PRESENT	equ 1		; SD card present
SD_WRTPROT	equ 2		; SD card is write protected
SD_M_DSKCHG	equ (1 shl SD_DSKCHG)		; bitmask for SD_DSKCHG
SD_M_PRESENT	equ (1 shl SD_PRESENT)		; bitmask for SD_PRESENT
SD_M_WRTPROT	equ (1 shl SD_WRTPROT)		; bitmask for SD_WRTPROT

; SPI commands: 
CMD0	equ 0  OR #40
CMD1	equ 1  OR #40
CMD8	equ 8  OR #40
CMD9	equ 9  OR #40
CMD10	equ 10 OR #40
CMD12	equ 12 OR #40
CMD13	equ 13 OR #40
CMD16	equ 16 OR #40
CMD17	equ 17 OR #40
CMD18	equ 18 OR #40
CMD24	equ 24 OR #40
CMD25	equ 25 OR #40
CMD55	equ 55 OR #40
CMD58	equ 58 OR #40
ACMD23	equ 23 OR #40
ACMD41	equ 41 OR #40

; SD card errors
R1ERR.IDLE	equ 1	; In idle state
R1ERR.ERARST	equ 2	; Erase reset
R1ERR.ILLGCMD	equ 3	; Illegal command
R1ERR.CRCERR	equ 4	; Communication CRC error
R1ERR.ERAERR	equ 5	; Erase sequence error
R1ERR.ADDRERR	equ 6	; Address error
R1ERR.PARMERR	equ 7	; Parameter error
R1ERR.M_IDLE	equ (1 shl R1ERR.IDLE)
R1ERR.M_ERARST	equ (1 shl R1ERR.ERARST)
R1ERR.M_ILLGCMD	equ (1 shl R1ERR.ILLGCMD)
R1ERR.M_CRCERR	equ (1 shl R1ERR.CRCERR)
R1ERR.M_ERAERR	equ (1 shl R1ERR.ERAERR)
R1ERR.M_ADDRERR	equ (1 shl R1ERR.ADDRERR)
R1ERR.M_PARMERR	equ (1 shl R1ERR.PARMERR)

WRKAREA.TRLDIR		equ 0			; Pointer to the R800 data transfer helper
WRKAREA.NUMSD		equ WRKAREA.TRLDIR+2		; Currently selected card: 1 or 2 
WRKAREA.CARDFLAGS	equ WRKAREA.NUMSD+1		; Flags that indicate card-change or card error 
					; b0: card1 error
					; b1: card2 error
					; b2: card1 LUN changed flag
					; b3: card2 LUN changed flag
					; b4: card1 DEV changed flag
					; b5: card2 DEV changed flag
					; b6: card1 version
					; b7: card2 version
WRKAREA.NUMBLOCKS	equ WRKAREA.CARDFLAGS+1		; Number of blocks in multi-block operations 
WRKAREA.TEMP		equ WRKAREA.NUMBLOCKS+1		; Buffer for temporary data 
WRKAREA.DSKEMU.DSKDEV	equ WRKAREA.TEMP+1		; Floppy emulation: b0~b2=DEV, b3~b7=Disk number 
;WRKAREA.DSKEMU.VDPDR	equ WRKAREA.DSKEMU.DSKDEV+1	; VDP.DR cached value
WRKAREA.DSKEMU.VDPDW	equ WRKAREA.DSKEMU.DSKDEV+1	; VDP.DW cached value
WRKAREA.END		equ WRKAREA.DSKEMU.VDPDW+1

; WRKAREA.CARDFLAGS shift amount and direction
WCF_N_ERROR	equ 0	; SD card error
WCF_L_LUNCHG	equ 2	; LUN has changed software flag
WCF_L_DEVCHG	equ 4	; Device has changed software flag
WCF_R_CRDVER	equ 2	; Current card version

CID.MID		equ 0			; Manufacturer ID
CID.OID		equ CID.MID+1		; OEM ID
CID.PNM		equ CID.OID+2		; Product Name
CID.PRV		equ CID.PNM+5
CID.PSN		equ CID.PRV+1		; Product Serial Number
CID.RSVMDT	equ CID.PSN+4		; Reserved, Manufacturing date
CID.CRC		equ CID.RSVMDT+2	; b7=1, b6~b0 = CRC7 checksum
CID.END		equ CID.CRC+1

;-----------------------------------------------------------------------------
;
; Standard BIOS and work area entries
CALSLT	equ #001C		; Call routine in any slot
CALLF	equ #0030		; Call routine in any slot
INITXT	equ #006C		; Inicializa SCREEN0
CHSNS	equ #009C		; Sense keyboard buffer for character
CHGET	equ #009F		; Get character from keyboard buffer
CHPUT	equ #00A2		; A=char
BEEP	equ #00C0		; Does a beep
CLS	equ #00C3		; Chamar com A=0
ERAFNK	equ #00CC		; Erase function key display
SNSMAT	equ #0141		; Read row of keyboard matrix
KILBUF	equ #0156		; Clear keyboard buffer
EXTROM	equ #015F
CHGCPU	equ #0180		; Change the turbo mode
GETCPU	equ #0183		; Get the turbo mode

; subROM functions
SDFSCR	equ #0185
REDCLK	equ #01F5


; System variables
VDP.DR	equ #0006
VDP.DW	equ #0007
MSXVER	equ #002D
LINL40	equ #F3AE		; Width
LINLEN	equ #F3B0
TEMP3	equ #F69D
INTFLG	equ #FC9B
SCRMOD	equ #FCAF
EXPTBL	equ #FCC1
RG15SA	equ #FFEE		; VDP Register 15 Save copy.
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

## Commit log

2021-01-15 Liberação para o público
2021-03-02 Added schematic.pdf
2022-12-02 Update driver.asm
    Added a comment about the ASCII16 ROM mapper and the page where the interface register set is enabled.
2023-12-06 Fixing case of filenames
    [DRIVER.ASM]
2023-12-17 fix: filename case
2024-02-15 Adding 3D case link
2024-05-03 Adding missing eagle files
    [sdmapper.brd, sdmapper.sch]
2024-07-01 Alterando PCB e gerbers para retirar o logo PalMal
    [sdmapper.brd]
2024-07-04 Corrigindo Gerbers

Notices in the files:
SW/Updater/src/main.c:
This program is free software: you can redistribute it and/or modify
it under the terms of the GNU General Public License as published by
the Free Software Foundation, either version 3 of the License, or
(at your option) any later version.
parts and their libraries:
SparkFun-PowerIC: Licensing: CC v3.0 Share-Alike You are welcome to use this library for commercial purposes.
